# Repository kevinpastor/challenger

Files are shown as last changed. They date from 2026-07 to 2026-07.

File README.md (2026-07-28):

# Challenger

A 35-key gaming keypad powered by ZMK.

## Features

- 35 MX-compatible keys
- Wireless (nice!nano)
- nice!view display
- Hotswap sockets

## Bill of Materials

### PCB

| Qty | Part | Description |
|-----|---|---|
| 1 | Challenger PCB | |
| 35 | MX switches (of your choice) |  |
| 35 | Kailh MX hot-swap sockets | Switch sockets |
| 35 | 1N4148W diodes | SMD switch diodes |
| 1 | [nice!nano v2](https://nicekeyboards.com/nice-nano/) | Wireless microcontroller |
| 2 | Mill-Max [315-43-112-41-003000](https://www.digikey.ca/en/products/detail/digikey-va/315-43-112-41-003000/4455232) | Female header, 12-pin, microcontroller socket |
| 2 | Mill-Max [350-10-112-00-006000](https://www.digikey.ca/en/products/detail/digikey-va/350-10-112-00-006000/4456133) | Pin header, 12-pin, microcontroller socket |
| 1 | Panasonic [EVQ-PUL02K](https://www.digikey.ca/en/products/detail/panasonic-industry/EVQ-PUL02K/286340) | Tactile switch, as the reset button |
| 1 | Alps Alpine [SSSS811101](https://www.digikey.ca/en/products/detail/alps-alpine/SSSS811101/19529062) | Slide switch, as the power switch |
| 1 | [3.7v 110mAh 301230 LiPo battery](https://www.aliexpress.com/item/1005005348368664.html) | Positive terminal must be on the right side of the connector
| 1 | JST [S2B-PH-K-S](https://www.digikey.ca/en/products/detail/jst-sales-america-inc/S2B-PH-K-S/926626) | Battery connector, 2-pin |

The [EVQ-PUJ02K](https://www.digikey.ca/en/products/detail/panasonic-industry/EVQ-PUJ02K/286338), the [EVQ-PUA02K](https://www.digikey.ca/en/products/detail/panasonic-industry/EVQ-PUA02K/286334), or the [EVQ-PUC02K](https://www.digikey.ca/en/products/detail/panasonic-industry/EVQ-PUC02K/286336) could be used instead for the reset button, since they only differ in operating force or boss (aligning plastic tab on the underside).

The battery connector model number can have a different last letter or no at all (e.g. [S2B-PH-K-K](https://www.digikey.ca/en/products/detail/jst-sales-america-inc/S2B-PH-K-K/27506616), S2B-PH-K-H, [S2B-PH-K](https://www.digikey.ca/en/products/detail/jst-sales-america-inc/S2B-PH-K/28540441)), which only represents its color.

### Case

| Qty | Part | Description |
|-----|---|---|
| 1 | Switch plate PCB | |
| 1 | Bottom plate PCB | |
| 4 | M2 x 7 mm standoffs | Case standoffs |
| 8 | M2 x 5 mm screws | Case screws |

M2 x 4 mm screws might be able to be used instead of the M2 x 5 mm screws.

### Display

> The display cover has not been designed yet. Some parts listed are for future reference.

| Qty | Part | Description |
|-----|---|---|
| 1 | [nice!view](https://nicekeyboards.com/nice-view) | Display |
| 2 | M2 x 10 mm standoffs | Cover standoffs |
| 2 | M2 x 5 mm screws | Cover standoff screws |

M2 x 4 mm screws might be able to be used instead of the M2 x 5 mm screws.

## Build

See the [build guide](docs/index.md) for step-by-step assembly instructions.

## Firmware

Built with [ZMK](https://zmk.dev).

## License

[MIT](LICENSE)

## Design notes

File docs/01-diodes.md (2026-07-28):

# 1. SMD Diodes

SMD diodes, bottom right pad pre-tinned
SMD diodes placed on the PCB
SMD diodes soldered

The 35 SMD diodes (1N4148W) go on the **back side** of the PCB.

**Diodes are polarized and orientation matters.** The line on the diode body must match the line marking on the PCB silkscreen. Getting this wrong will cause keys not to register.

1. Pre-tin the bottom right pad of every diode footprint by applying a small amount of solder to it. This is the pad you will use to hold the diode in place.
2. Hold a diode with tweezers in your left hand. Reheat the pre-tinned pad with the iron in your right hand, then slide the diode into position. The line on the diode body must align with the line on the PCB silkscreen.
3. Let the solder cool, then solder the second (left) pad.
4. Reflow the first pad to make sure it has a clean joint.
5. Work through all 35 diodes.

> **Verify:** Look at each diode from above. The line on the diode body should line up with the line on the silkscreen. A phone camera can help for a closer look.

---

Next: [Hotswap Sockets](02-hotswap-sockets.md)

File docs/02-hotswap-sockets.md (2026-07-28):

Previous: [SMD Diodes](01-diodes.md)

# 2. Hotswap Sockets

Hotswap sockets placed on the PCB
Hotswap sockets soldered

The 35 Kailh MX hotswap sockets go on the **back side** of the PCB, in the outlined footprints. The socket shape matches the footprint outline, so orientation is clear.

1. Place all sockets into their footprints.
2. Solder one pad on each socket first, pressing the socket flat with a finger or tweezers as you go. Sockets can pop up from the heat if not held down.
3. Go back and solder the second pad on all sockets.

> **Verify:** Press each socket with a fingernail. It should not move or wiggle. Check that both pads have solid, shiny joints with no bridges between them.

---

Next: [Reset Button](03-reset-button.md)

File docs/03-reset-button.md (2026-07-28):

Previous: [Hotswap Sockets](02-hotswap-sockets.md)

# 3. Reset Button

Reset button placed on the PCB
Reset button soldered

The reset button (Panasonic EVQ-PUL02K) goes on the **top side** of the PCB.

1. Place the reset button in its footprint. The legs only fit in one orientation.
2. Solder all four legs.

> **Verify:** Press the button. It should click and spring back.

---

Next: [Power Switch](04-power-switch.md)

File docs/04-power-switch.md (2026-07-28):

Previous: [Reset Button](03-reset-button.md)

# 4. Power Switch

Power switch placed on the PCB
Power switch soldered

The slide switch (Alps Alpine SSSS811101) goes on the **top side** of the PCB.

1. Place the switch in its footprint. The legs are asymmetric so it only fits one way.
2. Solder all the legs.

> **Verify:** Slide the switch back and forth. It should move smoothly between both positions.

---

Next: [nice!nano Socket (Mill-Max)](05-nicenano-socket.md)

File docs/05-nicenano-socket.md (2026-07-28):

Previous: [Power Switch](04-power-switch.md)

# 5. nice!nano Socket (Mill-Max)

Mill-Max female sockets inserted into the PCB
Mill-Max sockets soldered from the back

The Mill-Max female sockets let you remove the nice!nano later without desoldering. Install two 12-pin female headers (315-43-112-41-003000) on the **top side** of the PCB.

1. Insert both 12-pin female headers into the nice!nano footprint on the top side of the PCB.
2. To keep them aligned while soldering, insert the 12-pin pin headers (350-10-112-00-006000) into the sockets, then rest the nice!nano on top. This holds everything straight.
3. Flip the PCB over.
4. Solder the two corner pins of each socket first to lock them in place.
5. Check that the sockets are flush and straight, then solder the remaining pins.
6. Remove the pin headers and nice!nano. Do not solder them yet.

> **Warning:** Keep your iron at 300–320 °C for this step. The plastic housing can deform if overheated.

> **Verify:** The sockets should be flush against the PCB and not tilted. Check all 24 joints for clean, shiny joints and no bridges.

---

Next: [nice!view Socket](06-niceview-socket.md)

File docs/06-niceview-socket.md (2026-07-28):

Previous: [nice!nano Socket (Mill-Max)](05-nicenano-socket.md)

# 6. nice!view Socket

nice!view socket inserted into the PCB
nice!view socket soldered

The nice!view socket (5-pin) goes on the **top side** of the PCB.

1. Insert the 5-pin female socket into the nice!view footprint on the top side of the PCB.
2. Optionally secure it with a piece of tape.
3. Flip the PCB over and solder one pin.
4. Check that the socket is straight and flush, then solder the remaining 4 pins.

---

Next: [JST Battery Connector](07-jst-connector.md)

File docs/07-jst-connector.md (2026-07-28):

Previous: [nice!view Socket](06-niceview-socket.md)

# 7. JST Battery Connector

JST connector placed on the PCB
JST connector taped down before flipping
JST connector soldered from the bottom

The JST connector (S2B-PH-K-S) is a through-hole component that goes on the **top side** of the PCB, with its pins soldered from the bottom.

1. Insert the connector into its footprint on the top side. It only fits one way.
2. Tape the connector down so it stays seated when you flip the board.
3. Flip the PCB over and solder both pins from the bottom side.
4. Remove the tape.

> **Verify:** The connector should sit flush against the PCB and not wiggle.

---

Next: [Battery](08-battery.md)

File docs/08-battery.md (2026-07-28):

Previous: [JST Battery Connector](07-jst-connector.md)

# 8. Battery

> **Danger: Battery polarity is critical.** Plugging the battery in backwards can permanently damage the nice!nano and the PCB. **The positive (red) wire must be on the right side of the connector**, matching the marking on the PCB silkscreen. Double-check before plugging anything in.

Battery orientation
Battery plugged into JST connector

1. Make sure the **power switch is OFF** before connecting the battery.
2. Orient the battery so the yellow-taped side faces down.
3. Route the battery wires so they sit between the nice!nano socket and the nice!view socket.
4. Plug the JST connector into the jack on the PCB. It should click into place.
5. Tuck any excess wire carefully so it won't interfere with the switch plate.

> **Note:** To charge the battery, the power switch must be **ON**. The nice!nano does not charge the battery when the switch is off.

---

Next: [nice!nano](09-nicenano.md)

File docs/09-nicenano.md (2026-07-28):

Previous: [Battery](08-battery.md)

# 9. nice!nano

nice!nano placed on the pin headers
nice!nano soldered to the pin headers

Solder the pin headers to the nice!nano so it can plug into the Mill-Max sockets.

> **Warning:** Keep the iron at **270–300 °C** for this step. Higher temperatures can damage the nRF52840 chip on the nice!nano.

1. Insert the two 12-pin pin headers (short side down) into the Mill-Max sockets on the PCB.
2. Place the nice!nano **face down** (components and logo facing down, away from you) onto the pin headers.
3. Check that the USB-C port sits at the edge of the PCB.
4. Solder the two corner pins first while keeping the nice!nano flat and flush.
5. Solder the remaining 22 pins.
6. Lift the nice!nano straight up to remove it from the sockets. Pull evenly from both sides to avoid bending pins.

> **Tip:** Use a piece of Kapton tape to hold the nice!nano down while soldering the corner pins if it tends to shift.

> **Verify:** All 24 pins soldered, no bridges. The nice!nano seats snugly into the sockets and can be removed and reinserted cleanly.

---

Next: [nice!view](10-niceview.md)

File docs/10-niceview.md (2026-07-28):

Previous: [nice!nano](09-nicenano.md)

# 10. nice!view

nice!view pin headers soldered to the display
nice!view inserted into the PCB socket

1. Insert the **short side** of the 5-pin header into the underside of the nice!view. The long side will plug into the socket on the PCB.
2. Solder one pin, check that the header is straight and flush with the nice!view, then solder the remaining 4 pins.
3. Plug the nice!view into the socket on the PCB.

> **Note:** The display cover has not been designed yet. Leave the nice!view inserted for now and revisit once the cover is available.

---

Next: [Switches, Switch Plate & Case Assembly](11-switches-and-case.md)

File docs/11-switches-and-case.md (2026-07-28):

Previous: [nice!view](10-niceview.md)

# 11. Switches, Switch Plate & Case Assembly

The switch plate, PCB, and bottom plate are all held together by the same standoffs, so this all gets done in one go.

Standoffs screwed into the switch plate
Switches inserted into the switch plate
Switch plate assembly placed on the PCB
Bottom plate attached

1. Screw the four **M2 x 7 mm standoffs** into the **top side of the switch plate** using four **M2 x 5 mm screws**.
2. Insert all 35 switches into the switch plate. **MX switches: the pins face up** (toward the top of the plate).
3. Make sure all switch pins are straight. Bent pins will not seat into the hotswap sockets and can damage them.
4. Carefully lower the plate and switch assembly onto the PCB, lining up the switch pins with the hotswap sockets.
5. Press down firmly and evenly on each switch until it is fully seated. Each switch should sit flush against the PCB with no gaps.
6. Place the bottom plate against the underside of the standoffs and fasten it with the remaining four **M2 x 5 mm screws**.

> **Tip:** Press switches near the corners first to get the plate aligned, then work your way inward.

> **Tip:** Don't overtighten the screws. Snug is enough. Overtightening can crack PCB-based plates.

> **Verify:** None of the switches should wobble. The plate and PCB should sit flush with no gaps.

---

Next: [Keycaps](12-keycaps.md)

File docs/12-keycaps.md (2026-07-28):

Previous: [Switches, Switch Plate & Case Assembly](11-switches-and-case.md)

# 12. Keycaps

Keycaps installed on the switches

Line up each keycap with its switch stem and press down firmly until it clicks into place. That's it.

---

Next: [Flashing Firmware](13-firmware.md)

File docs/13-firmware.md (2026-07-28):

Previous: [Keycaps](12-keycaps.md)

# 13. Flashing Firmware

The Challenger runs [ZMK](https://zmk.dev). Flash the firmware before powering on for the first time.

1. Plug the nice!nano into your computer via USB-C.
2. Double-tap the reset button quickly. The nice!nano will appear as a USB drive called `NICENANO`.
3. Drag and drop the `.uf2` firmware file onto the `NICENANO` drive. Your OS may report an error when the transfer finishes; this is normal and can be ignored.
4. The drive will disappear and the nice!nano will reboot automatically.
5. Slide the power switch to **ON**.

> **Note:** If the `NICENANO` drive doesn't appear after double-tapping reset, try tapping faster. If the nice!nano has never been flashed before, a single tap is enough.

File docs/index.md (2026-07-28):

# Build Guide

This guide walks through building the Challenger from scratch. Follow the pages in order.

## Tools Required

Gather the following before you start:

- **Soldering iron** (temperature-controlled strongly recommended)
- **Solder** (63/37 or 60/40 leaded, 0.6–0.8 mm diameter is easiest for beginners; lead-free works too but requires a higher temperature)
- **Flux** (helps solder flow cleanly; especially useful for SMD components)
- **Flush cutters** (for trimming component legs)
- **Tweezers** (fine-tip, for handling small SMD components)
- **Isopropyl alcohol + brush** (for cleaning flux residue after soldering)
- **Kapton tape or painter's tape** (for holding components in place while soldering)

## Soldering Tips

If this is your first time soldering, read through [Adafruit's soldering guide](https://learn.adafruit.com/adafruit-guide-excellent-soldering) before starting.

A few key things to keep in mind:

- Set your iron to **300–320 °C** for leaded solder, **330–350 °C** for lead-free. Avoid going higher, heat damages components.
- Heat the pad and the leg together, then bring the solder in. Don't melt solder onto the iron tip and drip it on.
- A good joint looks shiny and slightly concave, like a small volcano. A dull, blobby joint is a cold joint; reheat it.
- Less is more with solder. You can always add more, but removing excess is harder.
- Keep your iron tip clean by wiping it on a wet sponge or brass wire cleaner often.

## Steps

1. [SMD Diodes](01-diodes.md)
2. [Hotswap Sockets](02-hotswap-sockets.md)
3. [Reset Button](03-reset-button.md)
4. [Power Switch](04-power-switch.md)
5. [nice!nano Socket (Mill-Max)](05-nicenano-socket.md)
6. [nice!view Socket](06-niceview-socket.md)
7. [JST Battery Connector](07-jst-connector.md)
8. [Battery](08-battery.md)
9. [nice!nano](09-nicenano.md)
10. [nice!view](10-niceview.md)
11. [Switches, Switch Plate & Case Assembly](11-switches-and-case.md)
12. [Keycaps](12-keycaps.md)
13. [Flashing Firmware](13-firmware.md)

---

Next: [SMD Diodes](01-diodes.md)

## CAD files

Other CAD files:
logo/challenger logo.FCStd

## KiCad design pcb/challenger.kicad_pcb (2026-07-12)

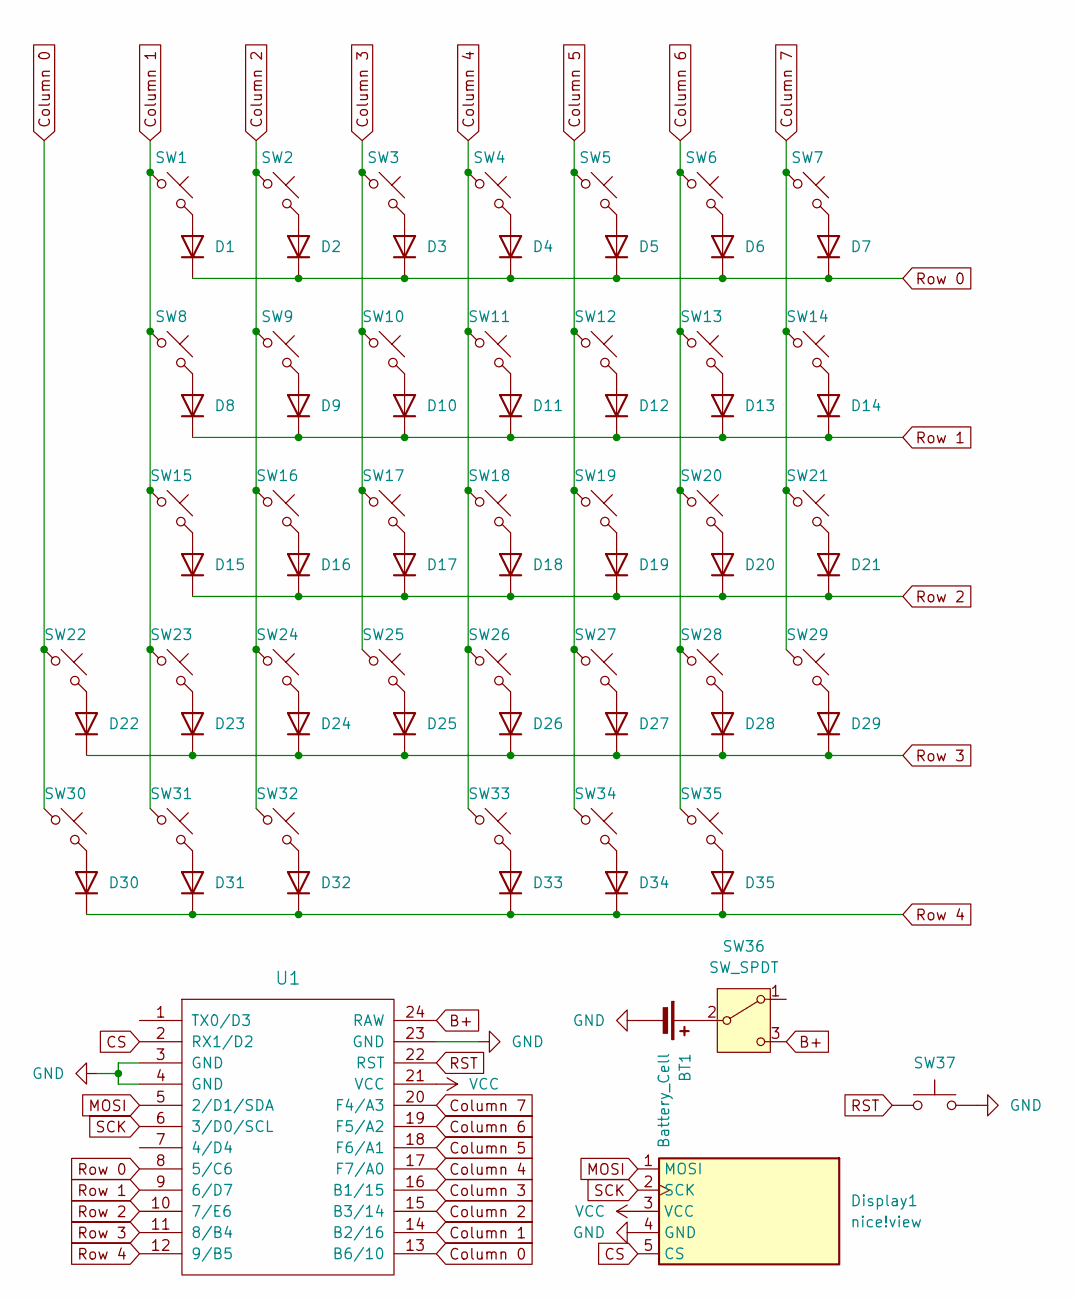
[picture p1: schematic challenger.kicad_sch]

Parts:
BT1: Battery_Cell; JST_PH_S2B-PH-K_1x02_P2.00mm_Horizontal
D1, D2, D3, D4, D5, D6, D7, D8, D9, D10, D11, D12, D13, D14, D15, D16, D17, D18, D19, D20, D21, D22, D23, D24, D25, D26, D27, D28, D29, D30, D31, D32, D33, D34, D35: 1N4148; D_SOD-123
Display1: nice!view; nice_view
SW1, SW2, SW3, SW4, SW5, SW6, SW7, SW8, SW9, SW10, SW11, SW12, SW13, SW14, SW15, SW16, SW17, SW18, SW19, SW20, SW21, SW22, SW23, SW24, SW25, SW26, SW27, SW28, SW29, SW30, SW31, SW32, SW33, SW34: SW_Push_45deg; Hotswap_MX_1.00u
SW35: SW_Push_45deg; Hotswap_MX_1.50u
SW36: SW_SPDT; SW_SPDT_PCM12
SW37: SW_Push; Panasonic_EVQPUL_EVQPUC
U1: ProMicro; nice_nano

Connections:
B+: SW36.3 (C), U1.24 (RAW)
CS: Display1.5 (CS), U1.2 (RX1/D2)
Column 0: SW22.1, SW30.1, U1.13 (B6/10)
Column 1: SW1.1, SW8.1, SW15.1, SW23.1, SW31.1, U1.14 (B2/16)
Column 2: SW2.1, SW9.1, SW16.1, SW24.1, SW32.1, U1.15 (B3/14)
Column 3: SW3.1, SW10.1, SW17.1, SW25.1, U1.16 (B1/15)
Column 4: SW4.1, SW11.1, SW18.1, SW26.1, SW33.1, U1.17 (F7/A0)
Column 5: SW5.1, SW12.1, SW19.1, SW27.1, SW34.1, U1.18 (F6/A1)
Column 6: SW6.1, SW13.1, SW20.1, SW28.1, SW35.1, U1.19 (F5/A2)
Column 7: SW7.1, SW14.1, SW21.1, SW29.1, U1.20 (F4/A3)
GND: BT1.2 (-), Display1.4 (GND), SW37.2, U1.3 (GND), U1.4 (GND), U1.23 (GND)
MOSI: Display1.1 (MOSI), U1.5 (2/D1/SDA)
unnamed: BT1.1 (+), SW36.2 (B)
unnamed: D1.2 (A), SW1.2
unnamed: D2.2 (A), SW2.2
unnamed: D3.2 (A), SW3.2
unnamed: D4.2 (A), SW4.2
unnamed: D5.2 (A), SW5.2
unnamed: D6.2 (A), SW6.2
unnamed: D7.2 (A), SW7.2
unnamed: D8.2 (A), SW8.2
unnamed: D9.2 (A), SW9.2
unnamed: D10.2 (A), SW10.2
unnamed: D11.2 (A), SW11.2
unnamed: D12.2 (A), SW12.2
unnamed: D13.2 (A), SW13.2
unnamed: D14.2 (A), SW14.2
unnamed: D15.2 (A), SW15.2
unnamed: D16.2 (A), SW16.2
unnamed: D17.2 (A), SW17.2
unnamed: D18.2 (A), SW18.2
unnamed: D19.2 (A), SW19.2
unnamed: D20.2 (A), SW20.2
unnamed: D21.2 (A), SW21.2
unnamed: D22.2 (A), SW22.2
unnamed: D23.2 (A), SW23.2
unnamed: D24.2 (A), SW24.2
unnamed: D25.2 (A), SW25.2
unnamed: D26.2 (A), SW26.2
unnamed: D27.2 (A), SW27.2
unnamed: D28.2 (A), SW28.2
unnamed: D29.2 (A), SW29.2
unnamed: D30.2 (A), SW30.2
unnamed: D31.2 (A), SW31.2
unnamed: D32.2 (A), SW32.2
unnamed: D33.2 (A), SW33.2
unnamed: D34.2 (A), SW34.2
unnamed: D35.2 (A), SW35.2
RST: SW37.1, U1.22 (RST)
Row 0: D1.1 (K), D2.1 (K), D3.1 (K), D4.1 (K), D5.1 (K), D6.1 (K), D7.1 (K), U1.8 (5/C6)
Row 1: D8.1 (K), D9.1 (K), D10.1 (K), D11.1 (K), D12.1 (K), D13.1 (K), D14.1 (K), U1.9 (6/D7)
Row 2: D15.1 (K), D16.1 (K), D17.1 (K), D18.1 (K), D19.1 (K), D20.1 (K), D21.1 (K), U1.10 (7/E6)
Row 3: D22.1 (K), D23.1 (K), D24.1 (K), D25.1 (K), D26.1 (K), D27.1 (K), D28.1 (K), D29.1 (K), U1.11 (8/B4)
Row 4: D30.1 (K), D31.1 (K), D32.1 (K), D33.1 (K), D34.1 (K), D35.1 (K), U1.12 (9/B5)
SCK: Display1.2 (SCK), U1.6 (3/D0/SCL)
VCC: Display1.3 (VCC), U1.21 (VCC)

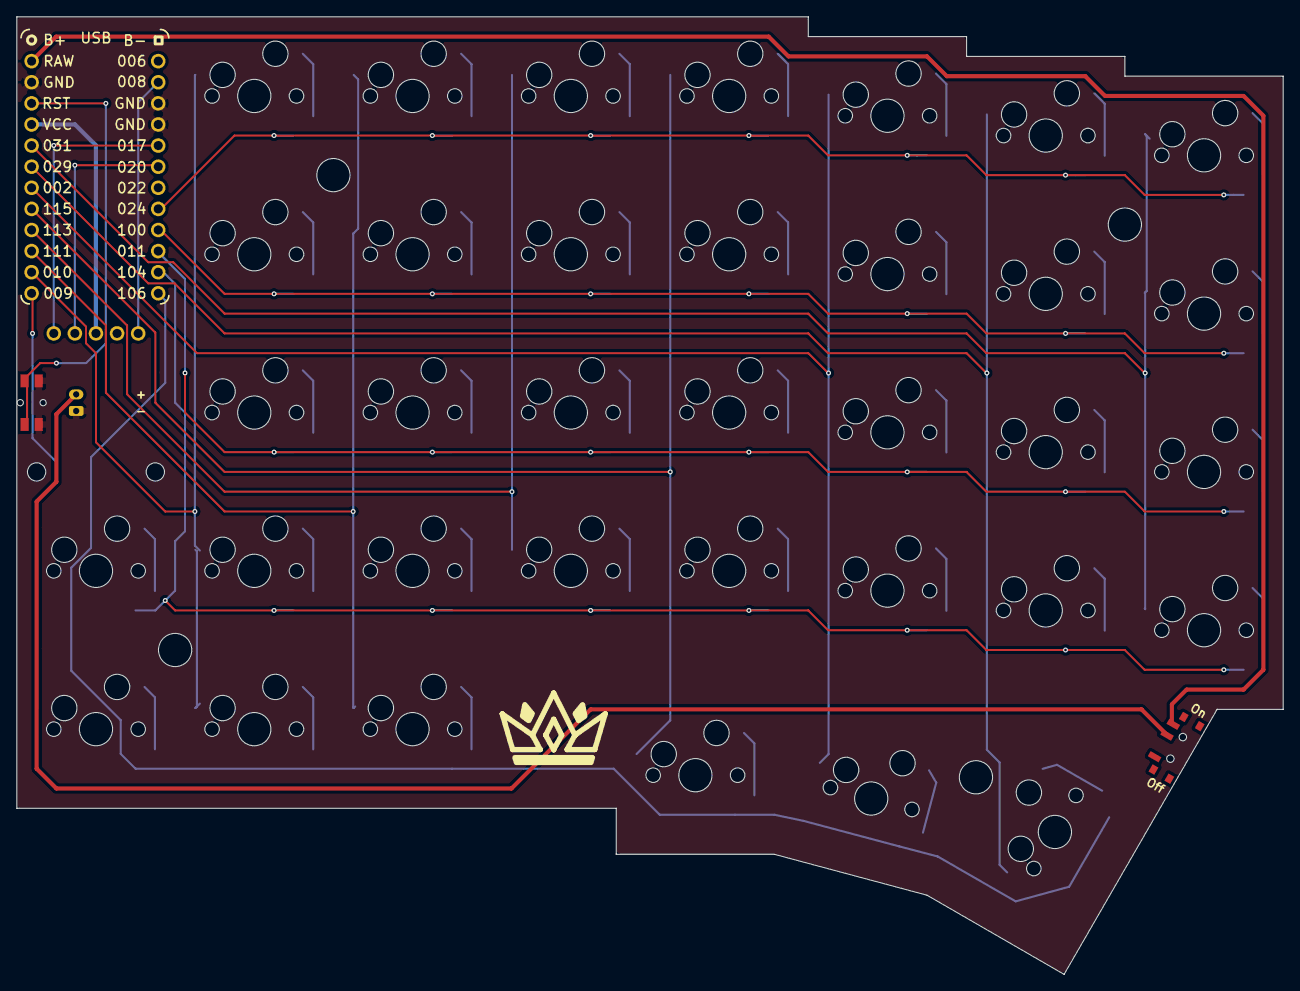
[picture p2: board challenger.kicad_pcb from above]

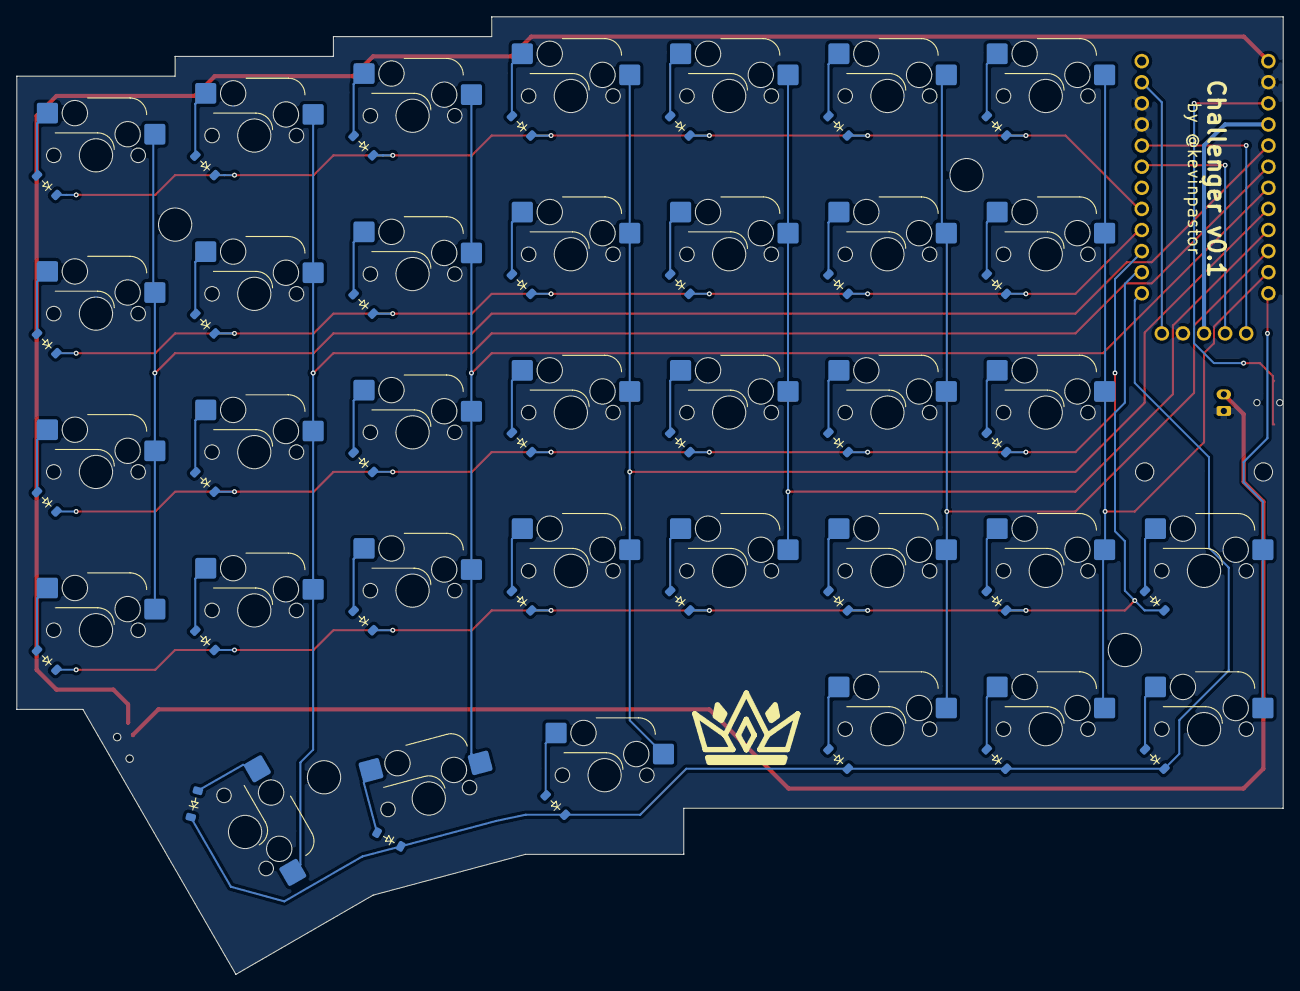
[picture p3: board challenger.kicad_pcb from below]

Board: 2 copper layers, 152.4 x 115.2 mm, 75 parts (36 on the bottom side), 56 nets.

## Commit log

2026-07-07 feat: initial commit
    [challenger.kicad_pcb, challenger.kicad_sch]
2026-07-07 feat: remove hybrid diode setup
    [challenger.kicad_pcb, challenger.kicad_sch]
2026-07-07 feat: update traces
    [challenger.kicad_pcb, challenger.kicad_sch]
2026-07-10 feat: add switch and bottom plates and refine pcb
    [bottom_plate.kicad_pcb, challenger.kicad_pcb, challenger.kicad_sch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]
2026-07-10 feat: touchups before review
    [challenger.kicad_sch]
2026-07-11 feat: update BOM
2026-07-11 feat: cleanup BOM
2026-07-12 feat: add logo and update font
    [challenger logo.FCStd, challenger.kicad_pcb]
2026-08-05 feat: add external power toggle
2026-08-16 fix: move spi config
2026-09-03 test: unflip board
